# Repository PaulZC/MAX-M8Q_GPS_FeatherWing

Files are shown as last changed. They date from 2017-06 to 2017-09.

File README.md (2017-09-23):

# MAX-M8Q GPS FeatherWing

A clone of the Adafruit Ultimate GPS FeatherWing but with the u-blox MAX-M8Q (external antenna) replacing the GlobalTop FGPMMOPA6H

**23-09-2017: Updated PCB now includes: pull-up resistors for SCL and SDA; a decoupling capacitor for VCC_RF; a test pad for SAFEBOOT**

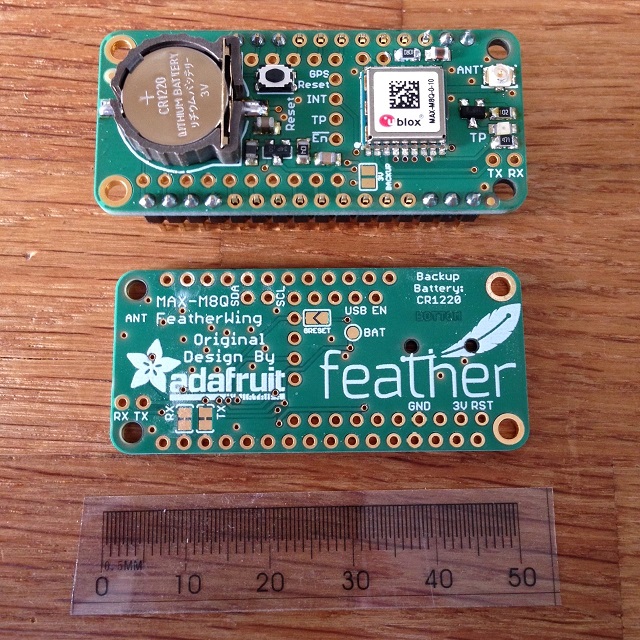
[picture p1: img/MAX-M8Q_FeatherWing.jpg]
MAX-M8Q_FeatherWing


See [MAX-M8Q_GPS_FeatherWing.pdf](https://github.com/PaulZC/MAX-M8Q_GPS_FeatherWing/blob/master/MAX-M8Q_GPS_FeatherWing.pdf) for the BOM etc.

The [Eagle](https://github.com/PaulZC/MAX-M8Q_GPS_FeatherWing/tree/master/Eagle) directory contains the schematic and pcb design

The [Arduino](https://github.com/PaulZC/MAX-M8Q_GPS_FeatherWing/tree/master/Arduino) directory contains code for the [Adafruit Feather M0 Adalogger](https://www.adafruit.com/products/2796) which will log your route to SD card in GPX and CSV format
- https://www.adafruit.com/products/2796
- https://learn.adafruit.com/adafruit-feather-m0-adalogger

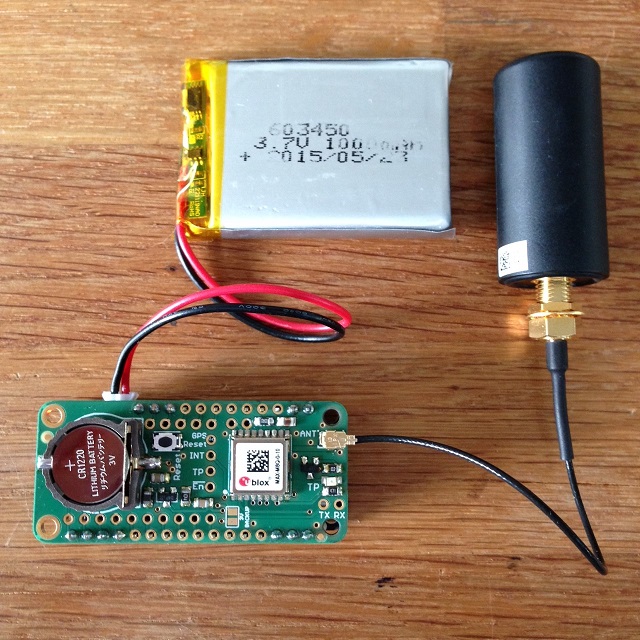
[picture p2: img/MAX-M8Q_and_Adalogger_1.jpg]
MAX-M8Q_and_Adalogger_1


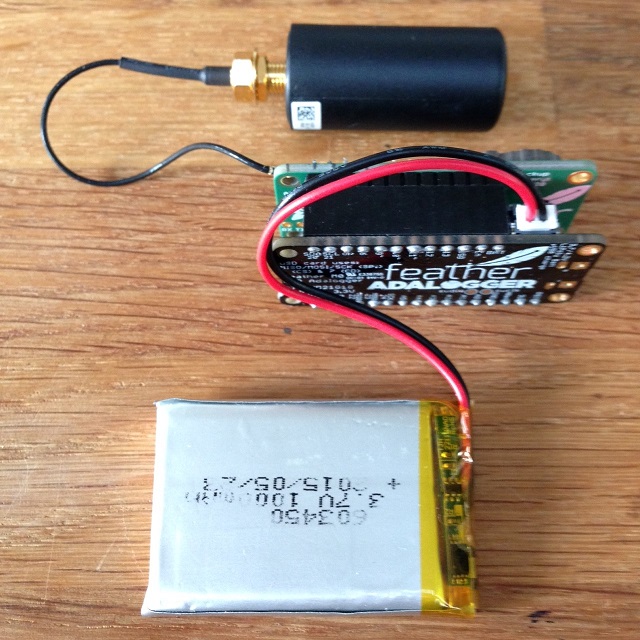
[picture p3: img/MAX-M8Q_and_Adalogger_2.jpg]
MAX-M8Q_and_Adalogger_2


Useful documentation about the MAX-M8Q and its protocol specification can be found at:
- https://www.u-blox.com/en/files/max-m8datasheetubx-13004644pdf
- https://www.u-blox.com/en/files/max-m8himubx-13004876pdf
- https://www.u-blox.com/en/files/u-bloxm8receiverdescrprotspecubx-13003221publicpdf

Based on an original design by Adafruit Industries:
- https://www.adafruit.com/product/3133
- https://learn.adafruit.com/adafruit-ultimate-gps-featherwing
- https://github.com/adafruit/Adafruit-Ultimate-GPS-FeatherWing-PCB

Distributed under a Creative Commons Attribution, Share-Alike license

Adafruit invests time and resources providing this open source design, please support Adafruit and open-source hardware by purchasing products from Adafruit!

Enjoy!

**_Paul_**

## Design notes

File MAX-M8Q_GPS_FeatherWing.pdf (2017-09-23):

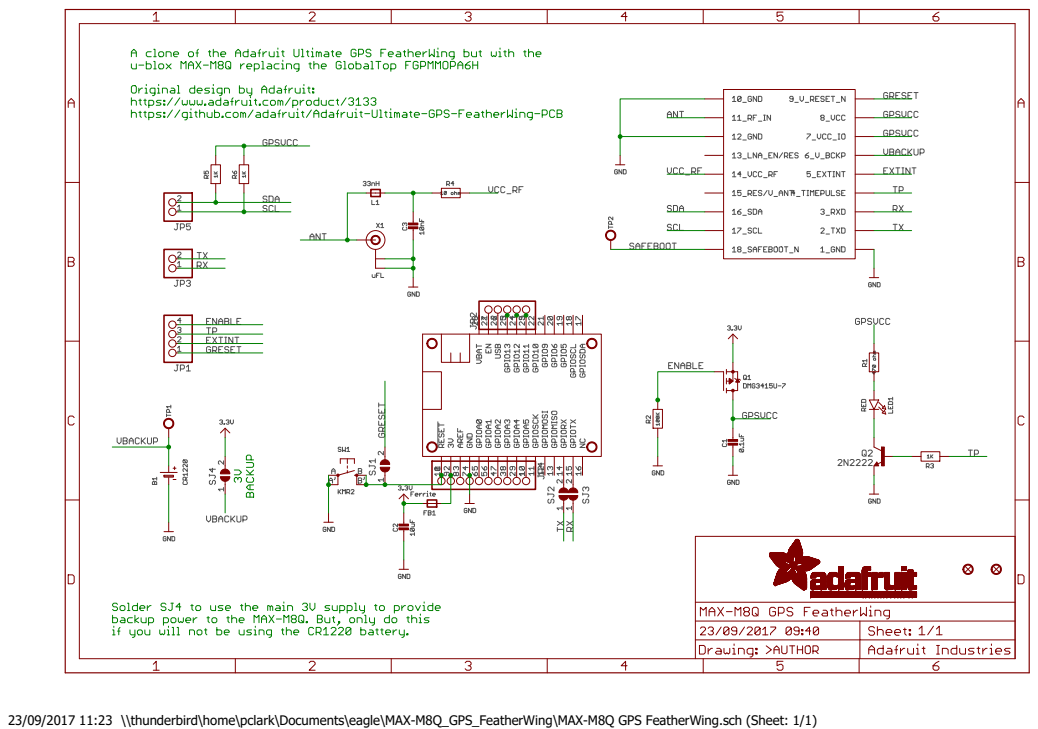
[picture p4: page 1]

23/09/2017 11:23 \\thunderbird\home\pclark\Documents\eagle\MAX-M8Q_GPS_FeatherWing\MAX-M8Q GPS FeatherWing.sch (Sheet: 1/1)

Name | X | Y | Angle Package | Value | Farnell /
| | | | | Element 14 | Comments
FID1 | 1.65 | 16.89 | 0 FIDUCIAL | 1MM
FID2 | 46.51 | 1.06 | 0 FIDUCIAL | 1MM
B1 | 10.38 | 12.83 | 0 CR1220 Holder | | 2064722 | e.g. Multicomp CH291‐1220LF
C1 | 27.43 | 6.55 | 180 0805 | 0.1uF | 2496944 | e.g. Walsin 0805B104K500CT
C2 | 20.19 | 10.29 | 0 0805 | 10uF | 2496998 | e.g. Walsin 0805F106Z100CT
C3 | 41.63 | 19.43 | 0 0805 | 10nF | 2496939 | e.g. Walsin 0805B103K500CT
FB1 | 18.41 | 7.22 | 90 0805 | Ferrite | 1635734 | e.g. Wurth Elektronik 742792031 (300R @ 100MHz)
L1 | 44.52 | 18.52 | 270 0805 | 33nH | 2286465 | e.g. Coilcraft 0805HT‐33NTGLB
LED1 | 48.3 | 7.06 | 90 0805 (2.0x1.25) RED | 1716768 | e.g. Multicomp OVS‐0808
Q1 | 21.46 | 7.24 | 180 SOT23‐WIDE | DMG3415U‐7 | 1843688 | e.g. Diodes Inc DMG3415U‐7
Q2 | 44.1 | 7.8 | 180 SOT23‐BEC | 2N2222 | 9846700 | e.g. Fairchild MMBT2222A
R1 | 48.4 | 5.25 | 180 0805 | 470 ohm | 9334572 | e.g. Multicomp MC01W08055470R
R2 | 24.51 | 7.37 | 90 0805 | 100K | 9333738 | e.g. Multicomp MC01W08055100K
R3 | 48.36 | 8.88 | 180 0805 | 1K | 9333711 | e.g. Multicomp MC01W080551K
R4 | 37.13 | 19.43 | 180 0805 | 10 ohm | 9332421 | e.g. Multicomp MC01W0805110R
R5 | 45.76 | 12.97 | 0 0805 | 1K | 9333711 | e.g. Multicomp MC01W080551K
R6 | 45.8 | 11.04 | 0 0805 | 1K | 9333711 | e.g. Multicomp MC01W080551K
SW1 | 21.21 | 16.26 | 180 4.6X2.8 | | 1605470 | e.g. Multicomp MCIPTG23K‐V
U1 | 36.6 | 12.45 | 270 MAX‐M8Q | MAX‐M8Q | https://www.u‐blox.com/en/product/max‐m8‐series
X1 | 48.11 | 16.03 | 270 U.FL | uFL | 3908021 | e.g. Hirose U.FL‐R‐SMT(01)

Extras

B1 | | | CR1220 | 3V Lithium | 2065165 | e.g. Multicomp CR1220
uFL to SMA Adaptor | 2448785 | e.g. RF Solutions CBA‐UFLSMA‐1

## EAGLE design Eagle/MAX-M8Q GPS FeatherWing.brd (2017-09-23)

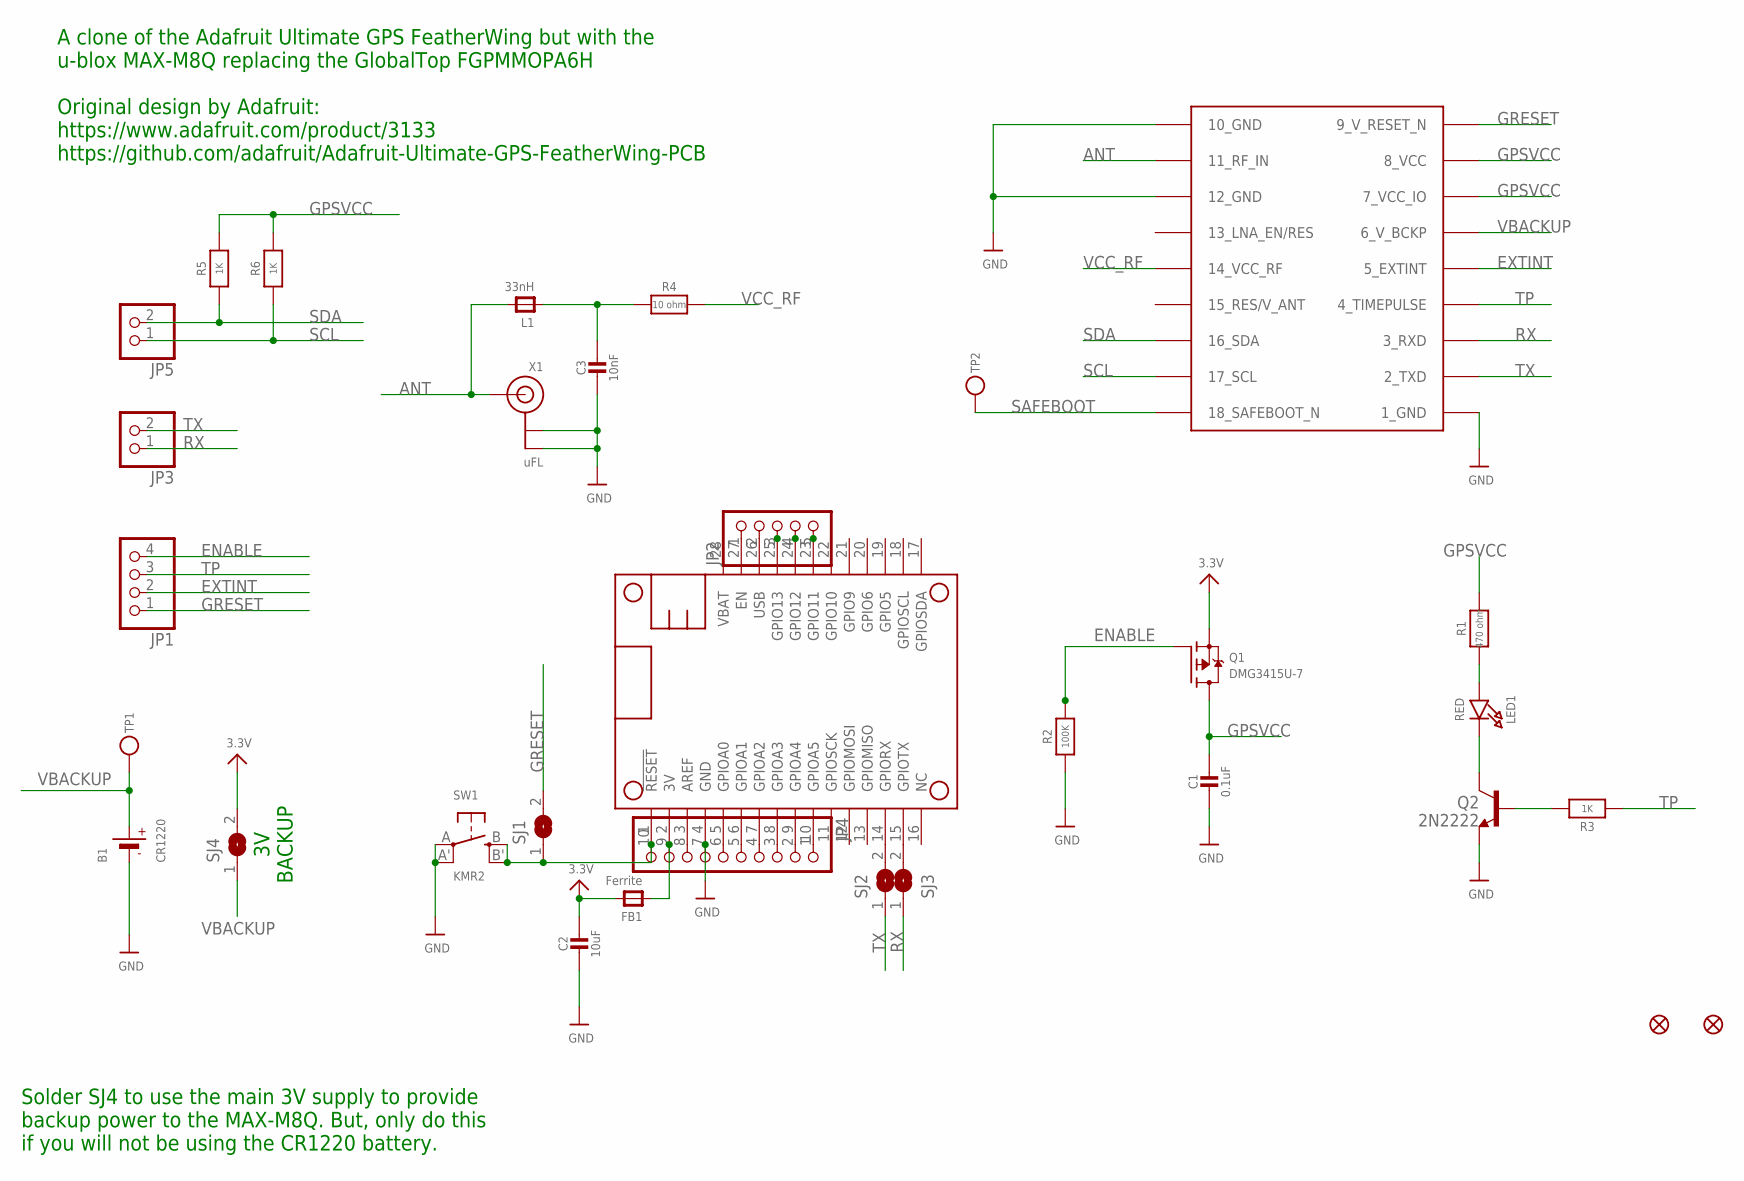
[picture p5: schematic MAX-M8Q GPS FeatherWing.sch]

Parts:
B1: CR1220; CR1220-2
C1: 0.1uF; 0805-NO
C2: 10uF; 0805-NO
C3: 10nF; 0805-NO
FB1: Ferrite; 0805-NO
FID1, FID2: FIDUCIAL""; FIDUCIAL_1MM
JP1: HEADER-1X4ROUND; 1X04_ROUND
JP2: HEADER-1X570MIL; 1X05_ROUND_70
JP3, JP5: HEADER-1X2ROUND; 1X02_ROUND
JP4: HEADER-1X10ROUND; 1X10_ROUND
L1: 33nH; 0805-NO
LED1: RED; CHIPLED_0805_NOOUTLINE
MS1: FEATHERWING
Q1: DMG3415U-7; SOT23-WIDE
Q2: 2N2222; SOT23-BEC
R1: 470 ohm; 0805-NO
R2: 100K; 0805-NO
R3, R5, R6: 1K; 0805-NO
R4: 10 ohm; 0805-NO
SJ1, SJ4: SOLDERJUMPER; SOLDERJUMPER_ARROW_NOPASTE
SJ2, SJ3: SOLDERJUMPERCLOSED; SOLDERJUMPER_CLOSEDWIRE
SW1: KMR2; BTN_KMR2_4.6X2.8
TP1, TP2: TESTPOINTROUND1.5MM; TESTPOINT_ROUND_1.5MM
U1: MAX-M8
X1: uFL; U.FL

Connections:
3.3V: C2.1, FB1.2, Q1.2 (S), SJ4.2
3V: FB1.1, JP4.9, MS1.2 (3V)
ANT: L1.2, U1.11_RF_IN, X1.3 (SIGNAL)
ENABLE: JP1.4, Q1.1 (G), R2.2
EXTINT: JP1.2, U1.5_EXTINT
GND: B1.-, C1.2, C2.2, C3.2, JP4.7, MS1.4 (GND), Q2.E, R2.1, SW1.A, SW1.A' (P1), U1.1_GND, U1.10_GND, U1.12_GND, X1.1 (GND), X1.2 (GND)
GPSVCC: C1.1, Q1.3 (D), R1.2, R5.2, R6.2, U1.7_VCC_IO, U1.8_VCC
GRESET: JP1.1, SJ1.2, U1.9_RESET_N (9_V_RESET_N)
unnamed: JP2.3, MS1.25 (GPIO13)
unnamed: LED1.A, R1.1
unnamed: JP2.4, MS1.24 (GPIO12)
unnamed: C3.1, L1.1, R4.1
unnamed: JP2.5, MS1.23 (GPIO11)
unnamed: JP4.1, MS1.10 (GPIOA5)
unnamed: JP4.2, MS1.9 (GPIOA4)
unnamed: JP4.3, MS1.8 (GPIOA3)
unnamed: JP4.4, MS1.7 (GPIOA2)
unnamed: JP4.5, MS1.6 (GPIOA1)
unnamed: JP4.6, MS1.5 (GPIOA0)
unnamed: JP4.10, MS1.1 (!RESET), SJ1.1, SW1.B (S), SW1.B' (S1)
unnamed: JP4.8, MS1.3 (AREF)
unnamed: JP2.1, MS1.27 (EN)
unnamed: MS1.14 (GPIORX), SJ2.2
unnamed: MS1.15 (GPIOTX), SJ3.2
unnamed: LED1.C, Q2.C
unnamed: Q2.B, R3.2
RX: JP3.1, SJ3.1, U1.3_RXD
SAFEBOOT: TP2.P$1, U1.18_SAFEBOOT_N
SCL: JP5.1, R6.1, U1.17_SCL
SDA: JP5.2, R5.1, U1.16_SDA
TP: JP1.3, R3.1, U1.4_TIMEPULSE
TX: JP3.2, SJ2.1, U1.2_TXD
USB: JP2.2, MS1.26 (USB)
VBACKUP: B1.+, SJ4.1, TP1.P$1, U1.6_V_BCKP
VCC_RF: R4.2, U1.14_VCC_RF

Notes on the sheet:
A clone of the Adafruit Ultimate GPS FeatherWing but with the u-blox MAX-M8Q replacing the GlobalTop FGPMMOPA6H Original design by Adafruit: https://www.adafruit.com/product/3133 https://github.com/adafruit/Adafruit-Ultimate-GPS-FeatherWing-PCB
3V BACKUP
Solder SJ4 to use the main 3V supply to provide backup power to the MAX-M8Q. But, only do this if you will not be using the CR1220 battery.

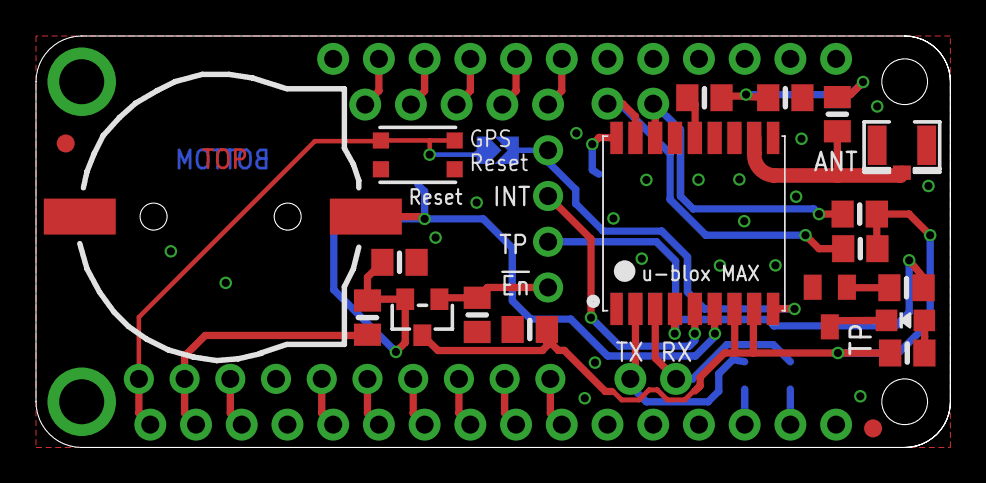
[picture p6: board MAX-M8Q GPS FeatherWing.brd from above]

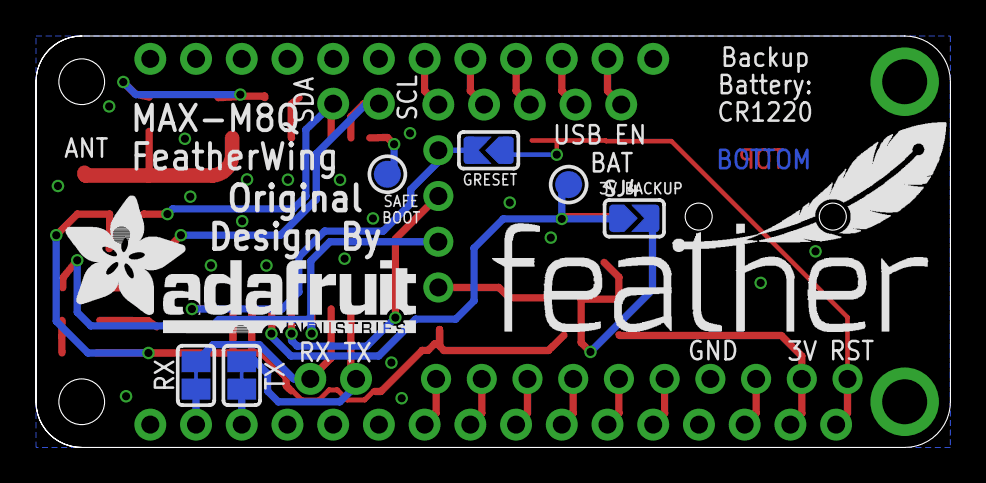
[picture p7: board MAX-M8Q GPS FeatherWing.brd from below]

Board: 2 copper layers, 50.8 x 22.9 mm, 32 parts (6 on the bottom side), 35 nets.

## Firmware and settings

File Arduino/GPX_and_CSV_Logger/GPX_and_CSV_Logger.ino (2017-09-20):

// Log GPS position to SD card in GPX track and CSV format

// This code is written for the Adalogger M0 Feather
// https://www.adafruit.com/products/2796
// and is based extensively on Adafruit's GPS_HardwareSerial_Parsing example
// https://github.com/adafruit/Adafruit_GPS/tree/master/examples/GPS_HardwareSerial_Parsing

// Works with both the Adafruit Ultimate GPS FeatherWing
// https://www.adafruit.com/product/3133
// and Paul's u-blox M8 FeatherWings
// https://github.com/PaulZC/SAM-M8Q_GPS_FeatherWing
// https://github.com/PaulZC/MAX-M8Q_GPS_FeatherWing

#define UBLOX // Comment this line out to select the Adafruit Ultimate GPS
//#define LOWPOWER // Comment this line out to disable u-blox M8 low power mode

// Leave the "#define GALILEO" uncommented to use: GPS + Galileo + GLONASS + SBAS
// Comment the "#define GALILEO" out to use the default u-blox M8 GNSS: GPS + SBAS + QZSS + GLONASS
#define GALILEO

//#define DEBUG // Comment this line out to disable extra serial debug messages

// Connect a normally-open push-to-close switch between swPin and GND.
// Press it to stop logging.
#define swPin 15 // Digital Pin 15 (0.2" away from the GND pin on the Adalogger)

// Include the Adafruit GPS Library
// https://github.com/adafruit/Adafruit_GPS
#include <Adafruit_GPS.h>
Adafruit_GPS GPS(&Serial1); // M0 hardware serial
     
// Set GPSECHO to 'false' to turn off echoing the GPS data to the Serial console
// Set to 'true' if you want to debug and listen to the raw GPS sentences
#define GPSECHO false
     
// this keeps track of whether we're using the interrupt
// off by default!
boolean usingInterrupt = false;

// SD card logging
#include <SPI.h>
#include <SD.h>
#define cardSelect 4
File gpx_dataFile;
File csv_dataFile;
char gpx_filename[] = "20000000/000000.gpx";
char csv_filename[] = "20000000/000000.csv";
char dirname[] = "20000000";
boolean fileReady = false;

// LEDs
#define RedLED 13 // The red LED on the Adalogger is connected to Digital Pin 13
#define GreenLED 8 // The green LED on the Adalogger is connected to Digital Pin 8

// Count number of valid fixes before starting to log (to avoid possible corrupt file names)
int valfix = 0;
#define maxvalfix 4 // Collect at least this many valid fixes before logging starts (must be >= 2)

// Track Point
long trkpt = 0;

#ifdef UBLOX // Definitions for u-blox M8 UBX-format (binary) messages

// Set Nav Mode to Portable
static const uint8_t setNavPortable[] = {
  0xB5, 0x62, 0x06, 0x24, 0x24, 0x00, 0xFF, 0xFF, 0x00, 0x03, 0x00, 0x00, 0x00, 0x00, 0x10, 0x27, 0x00, 0x00, 
  0x05, 0x00, 0xFA, 0x00, 0xFA, 0x00, 0x64, 0x00, 0x2C, 0x01, 0x00, 0x00, 0x00, 0x00, 0x00, 0x00, 0x00, 0x00, 
  0x00, 0x00, 0x00, 0x00, 0x00, 0x00 };
static const int len_setNav = 42;

// Set Nav Mode to Pedestrian
static const uint8_t setNavPedestrian[] = {
  0xB5, 0x62, 0x06, 0x24, 0x24, 0x00, 0xFF, 0xFF, 0x03, 0x03, 0x00, 0x00, 0x00, 0x00, 0x10, 0x27, 0x00, 0x00, 
  0x05, 0x00, 0xFA, 0x00, 0xFA, 0x00, 0x64, 0x00, 0x2C, 0x01, 0x00, 0x00, 0x00, 0x00, 0x00, 0x00, 0x00, 0x00, 
  0x00, 0x00, 0x00, 0x00, 0x00, 0x00 };

// Set Nav Mode to Automotive
static const uint8_t setNavAutomotive[] = {
  0xB5, 0x62, 0x06, 0x24, 0x24, 0x00, 0xFF, 0xFF, 0x04, 0x03, 0x00, 0x00, 0x00, 0x00, 0x10, 0x27, 0x00, 0x00, 
  0x05, 0x00, 0xFA, 0x00, 0xFA, 0x00, 0x64, 0x00, 0x2C, 0x01, 0x00, 0x00, 0x00, 0x00, 0x00, 0x00, 0x00, 0x00, 
  0x00, 0x00, 0x00, 0x00, 0x00, 0x00 };

// Set Nav Mode to Sea
static const uint8_t setNavSea[] = {
  0xB5, 0x62, 0x06, 0x24, 0x24, 0x00, 0xFF, 0xFF, 0x05, 0x03, 0x00, 0x00, 0x00, 0x00, 0x10, 0x27, 0x00, 0x00, 
  0x05, 0x00, 0xFA, 0x00, 0xFA, 0x00, 0x64, 0x00, 0x2C, 0x01, 0x00, 0x00, 0x00, 0x00, 0x00, 0x00, 0x00, 0x00, 
  0x00, 0x00, 0x00, 0x00, 0x00, 0x00 };

// Set Nav Mode to Airborne <1G
static const uint8_t setNavAir[] = {
  0xB5, 0x62, 0x06, 0x24, 0x24, 0x00, 0xFF, 0xFF, 0x06, 0x03, 0x00, 0x00, 0x00, 0x00, 0x10, 0x27, 0x00, 0x00, 
  0x05, 0x00, 0xFA, 0x00, 0xFA, 0x00, 0x64, 0x00, 0x2C, 0x01, 0x00, 0x00, 0x00, 0x00, 0x00, 0x00, 0x00, 0x00, 
  0x00, 0x00, 0x00, 0x00, 0x00, 0x00 };

// Set NMEA Config
// Set trackFilt to 1 to ensure course (COG) is always output
// Set Main Talker ID to 'GP' instead of 'GN'
static const uint8_t setNMEA[] = {
  0xb5, 0x62, 0x06, 0x17, 0x14, 0x00, 0x20, 0x40, 0x00, 0x02, 0x00, 0x00, 0x00, 0x00, 0x00, 0x01, 0x01, 0x01,
  0x00, 0x00, 0x00, 0x00, 0x00, 0x00, 0x00, 0x00 };
static const int len_setNMEA = 26;

// Set Low Power Mode
// Use this with caution
// Putting the M8 into low power mode before a fix has been established can cause it to reset after 10secs (searchPeriod)
static const uint8_t setLP[] = { 0xb5, 0x62, 0x06, 0x11, 0x02, 0x00, 0x48, 0x01 };
static const int len_setLP = 8;

// Set GNSS Config to GPS + Galileo + GLONASS + SBAS (Causes the M8 to restart!)
static const uint8_t setGNSS[] = {
  0xb5, 0x62, 0x06, 0x3e, 0x3c, 0x00,
  0x00, 0x20, 0x20, 0x07,
  0x00, 0x08, 0x10, 0x00, 0x01, 0x00, 0x01, 0x01,
  0x01, 0x01, 0x03, 0x00, 0x01, 0x00, 0x01, 0x01,
  0x02, 0x04, 0x08, 0x00, 0x01, 0x00, 0x01, 0x01,
  0x03, 0x08, 0x10, 0x00, 0x00, 0x00, 0x01, 0x01,
  0x04, 0x00, 0x08, 0x00, 0x00, 0x00, 0x01, 0x03,
  0x05, 0x00, 0x03, 0x00, 0x00, 0x00, 0x01, 0x05,
  0x06, 0x08, 0x0e, 0x00, 0x01, 0x00, 0x01, 0x01 };
static const int len_setGNSS = 66;

// Send message in u-blox UBX format
// Calculates and appends the two checksum bytes
// Doesn't add the 0xb5 and 0x62 sync chars (these need to be included at the start of the message)
void sendUBX(const uint8_t *message, const int len) {
  int csum1 = 0; // Checksum bytes
  int csum2 = 0;
#ifdef DEBUG
    Serial.print("Sending UBX packet: 0x");
#endif
  for (int i=0; i<len; i++) { // For each byte in the message
    Serial1.write(message[i]); // Write the byte
#ifdef DEBUG // DEBUG: print the message byte in HEX format
    if (message[i] < 16) {Serial.print("0");}
    Serial.print(message[i], HEX);
    Serial.print(", 0x");
#endif
    if (i >= 2) { // Don't include the sync chars in the checksum
      csum1 = csum1 + message[i]; // Update the checksum bytes
      csum2 = csum2 + csum1;
    }
  }
  csum1 = csum1 & 0xff; // Limit checksums to 8-bits
  csum2 = csum2 & 0xff;
  Serial1.write((uint8_t)csum1); // Send the checksum bytes
  Serial1.write((uint8_t)csum2);
#ifdef DEBUG // DEBUG: print the checksum bytes in HEX format
  if (csum1 < 16) {Serial.print("0");}
  Serial.print((uint8_t)csum1, HEX);
  Serial.print(", 0x");
  if (csum2 < 16) {Serial.print("0");}
  Serial.println((uint8_t)csum2, HEX);
#endif
}

#endif

void setup()
{
  // initialize digital pins RedLED and GreenLED as outputs.
  pinMode(RedLED, OUTPUT); // Red LED
  pinMode(GreenLED, OUTPUT); // Green LED
  // flash red and green LEDs on reset
  for (int i=0; i <= 4; i++) {
    digitalWrite(RedLED, HIGH);
    delay(200);
    digitalWrite(RedLED, LOW);
    digitalWrite(GreenLED, HIGH);
    delay(200);
    digitalWrite(GreenLED, LOW);
  }

  // initialize swPin as an input for the stop switch
  pinMode(swPin, INPUT_PULLUP);

  delay(10000); // Allow 10 sec for user to open serial monitor
  
  // connect at 115200 so we can read the GPS fast enough and echo without dropping chars
  Serial.begin(115200);
  Serial.println("Log GPS Position to SD card in GPX and CSV format");
  Serial.println("Green LED = GPS Fix");
  Serial.println("Red LED Flash = SD Write");
  Serial.println("Continuous Red indicates a problem or that the stop button has been pressed.");

  Serial.println("Initializing GPS...");

#ifdef UBLOX

  // u-blox M8 Init
  // 9600 is the default baud rate for u-blox M8
  GPS.begin(9600);
  // Disable all messages except GGA and RMC
  GPS.sendCommand("$PUBX,40,GLL,0,0,0,0*5C"); // Disable GLL
  delay(100);
  GPS.sendCommand("$PUBX,40,ZDA,0,0,0,0*44"); // Disable ZDA
  delay(100);
  GPS.sendCommand("$PUBX,40,VTG,0,0,0,0*5E"); // Disable VTG
  delay(100);
  GPS.sendCommand("$PUBX,40,GSV,0,0,0,0*59"); // Disable GSV
  delay(100);
  GPS.sendCommand("$PUBX,40,GSA,0,0,0,0*4E"); // Disable GSA
  delay(100);
  GPS.sendCommand("$PUBX,40,GGA,0,5,0,0*5F");  // Set GPGGA message rate to 5 (secs) - comment out for 1 sec logging
  delay(100);
  GPS.sendCommand("$PUBX,40,RMC,0,5,0,0*42");  // Set GPRMC message rate to 5 (secs) - comment out for 1 sec logging
  delay(100);
  sendUBX(setNavPortable, len_setNav); // Set Portable Navigation Mode
  //sendUBX(setNavPedestrian, len_setNav); // Set Pedestrian Navigation Mode
  //sendUBX(setNavAutomotive, len_setNav); // Set Automotive Navigation Mode
  //sendUBX(setNavSea, len_setNav); // Set Sea Navigation Mode
  //sendUBX(setNavAir, len_setNav); // Set Airborne <1G Navigation Mode
  delay(100);
  sendUBX(setNMEA, len_setNMEA); // Set NMEA configuration (use GP prefix instead of GN otherwise parsing will fail)
#ifdef GALILEO
  delay(100);
  sendUBX(setGNSS, len_setGNSS); // Set GNSS - causes M8 to restart!
  delay(2000); // Wait an extra 2 seconds for GNSS to restart
#endif
  delay(1100);
  while(Serial1.available()){Serial1.read();} // Flush RX buffer so we don't confuse GPS.parse with UBX acknowledgements

#else

  // Adafruit Ultimate GPS Init
  // 9600 NMEA is the default baud rate for Adafruit MTK GPS's- some use 4800
  GPS.begin(9600);
  // turn on RMC (recommended minimum) and GGA (fix data) including altitude
  GPS.sendCommand(PMTK_SET_NMEA_OUTPUT_RMCGGA);
  // Set the update rate
  //GPS.sendCommand(PMTK_SET_NMEA_UPDATE_1HZ); // 1 Hz update rate
  GPS.sendCommand(PMTK_SET_NMEA_UPDATE_200_MILLIHERTZ); // 5 sec update rate
  // Disable updates on antenna status
  GPS.sendCommand(PGCMD_NOANTENNA);

#endif

  Serial.println("GPS initialized!");

  // flash the red LED during SD initialisation
  digitalWrite(RedLED, HIGH);

  // Initialise SD card
  Serial.println("Initializing SD card...");
  // See if the SD card is present and can be initialized:
  if (!SD.begin(cardSelect)) {
    Serial.println("Panic!! SD Card Init failed, or not present!");
    // don't do anything more:
    while(1);
  }
  Serial.println("SD Card initialized!");

  // turn red LED off
  digitalWrite(RedLED, LOW);

  Serial.println("Waiting for GPS fix...");
}
     
void loop() // run over and over again
{
  // Check if stop switch has been pressed
  if (digitalRead(swPin) == LOW) {
    Serial.println("Stop switch pressed! Waiting for reset...");
    digitalWrite(RedLED, HIGH); // turn the red led on
    while(1); // wait for reset
  }
  
  // read data from the GPS in the 'main loop'
  char c = GPS.read();
  // if you want to debug, this is a good time to do it!
  if (GPSECHO)
    if (c) Serial.print(c);
  // if a sentence is received, we can check the checksum, parse it...
  if (GPS.newNMEAreceived()) {
    // Let the arrival of an new NMEA message be our second marker
    char *lastNMEA = GPS.lastNMEA(); // Make a copy of the string in case a new one arrives during parse (possibly redundant?)
    if (!GPS.parse(lastNMEA)) // this also sets the newNMEAreceived() flag to false
      return; // we can fail to parse a sentence in which case we should just wait for another

    // Choose whether to log on the arrival of the GGA or the RMC message
    // (choose whichever one is sent out second by the GPS)
#ifdef UBLOX
    if (strstr(lastNMEA,"$GPGGA")) { // u-blox M8: wait for a new GGA message
#else
    if (strstr(lastNMEA,"$GPRMC")) { // Ultimate GPS: wait for a new RMC message
#endif

#ifdef DEBUG
      Serial.print("\nTime: ");
      Serial.print(GPS.hour, DEC); Serial.print(':');
      Serial.print(GPS.minute, DEC); Serial.print(':');
      Serial.print(GPS.seconds, DEC); Serial.print('.');
      Serial.println(GPS.milliseconds);
      Serial.print("Date: ");
      Serial.print(GPS.day, DEC); Serial.print('/');
      Serial.print(GPS.month, DEC); Serial.print("/20");
      Serial.println(GPS.year, DEC);
      Serial.print("Fix: "); Serial.print((int)GPS.fix);
      Serial.print(" Quality: "); Serial.println((int)GPS.fixquality);
      if (GPS.fix) {
        Serial.print("Location: ");
        Serial.print(GPS.latitude, 4); Serial.print(GPS.lat);
        Serial.print(", ");
        Serial.print(GPS.longitude, 4); Serial.println(GPS.lon);
        Serial.print("Speed (knots): "); Serial.println(GPS.speed);
        Serial.print("Angle: "); Serial.println(GPS.angle);
        Serial.print("Altitude: "); Serial.println(GPS.altitude);
        Serial.print("Satellites: "); Serial.println((int)GPS.satellites);
        Serial.print("HDOP: "); Serial.println(GPS.HDOP);
      }
#endif

      // read battery voltage
      float vbat = analogRead(A7) * (2.0 * 3.3 / 1023.0);
#ifdef DEBUG
      Serial.print("Battery(V): ");
      Serial.println(vbat, 2);
#endif
    
      // turn green LED on to indicate GPS fix
      if (GPS.fix) {
        digitalWrite(GreenLED, HIGH);
        // increment valfix and cap at maxvalfix
        // don't do anything fancy in terms of decrementing valfix as we want to keep logging even if the fix is lost
        valfix += 1;
        if (valfix > maxvalfix) valfix = maxvalfix;
      }
      else {
        digitalWrite(GreenLED, LOW);
      }

#ifdef UBLOX
#ifdef LOWPOWER
      // Check if Low Power Mode can be started on the u-blox M8
      if (valfix == (maxvalfix - 1)) { // Only do this once
        sendUBX(setLP, len_setLP);
      }
#endif
#endif

      if (valfix == maxvalfix) { // wait until we have enough valid fixes to avoid possible filename corruption

        // do the divides once to save time
        char GPShourT = GPS.hour/10 + '0';
        char GPShourU = GPS.hour%10 + '0';
        char GPSminT = GPS.minute/10 + '0';
        char GPSminU = GPS.minute%10 + '0';
        char GPSsecT = GPS.seconds/10 + '0';
        char GPSsecU = GPS.seconds%10 + '0';
        char GPSyearT = GPS.year/10 +'0';
        char GPSyearU = GPS.year%10 +'0';
        char GPSmonT = GPS.month/10 +'0';
        char GPSmonU = GPS.month%10 +'0';
        char GPSdayT = GPS.day/10 +'0';
        char GPSdayU = GPS.day%10 +'0';

        // build the gpx data string
        String gpx_dataString = "<trkpt lat=\"";
        gpx_dataString += String(GPS.latitudeDegrees, 6);
        gpx_dataString += "\" lon=\"";
        gpx_dataString += String(GPS.longitudeDegrees, 6);
        gpx_dataString += "\">\n";
        gpx_dataString += "<name>";
        gpx_dataString += String(trkpt);
        gpx_dataString += "</name>\n";
        gpx_dataString += "<time>20";
        gpx_dataString += GPSyearT; gpx_dataString += GPSyearU; gpx_dataString += "-";
        gpx_dataString += GPSmonT; gpx_dataString += GPSmonU; gpx_dataString += "-";
        gpx_dataString += GPSdayT; gpx_dataString += GPSdayU; gpx_dataString += "T";
        gpx_dataString += GPShourT; gpx_dataString += GPShourU; gpx_dataString += ":";
        gpx_dataString += GPSminT; gpx_dataString += GPSminU; gpx_dataString += ":";
        gpx_dataString += GPSsecT; gpx_dataString += GPSsecU; gpx_dataString += ".";
        gpx_dataString += String((int)GPS.milliseconds); gpx_dataString += "Z</time>\n";
        gpx_dataString += "<ele>";
        gpx_dataString += String(GPS.altitude, 1);
        gpx_dataString += "</ele>\n";
        gpx_dataString += "<fix>";
        if (!GPS.fix) {
          gpx_dataString += "none";
        }
        else {
          gpx_dataString += "3d";
        }
        gpx_dataString += "</fix>\n";
        gpx_dataString += "<sat>";
        gpx_dataString += String((int)GPS.satellites);
        gpx_dataString += "</sat>\n";
        gpx_dataString += "<hdop>";
        gpx_dataString += String(GPS.HDOP, 2);
        gpx_dataString += "</hdop>\n";
        gpx_dataString += "<desc>Battery voltage ";
        gpx_dataString += String(vbat, 2);
        gpx_dataString += "V</desc>\n";
        gpx_dataString += "</trkpt>\n";

        // build the csv data string
        String csv_dataString = "";
        csv_dataString += GPShourT; csv_dataString += GPShourU; csv_dataString += ':';
        csv_dataString += GPSminT; csv_dataString += GPSminU; csv_dataString += ':';
        csv_dataString += GPSsecT; csv_dataString += GPSsecU;
        //csv_dataString += '.'; csv_dataString += String(GPS.milliseconds, DEC); // comment this line out to ignore milliseconds
        csv_dataString += ' '; // separate time and date with a space (not a ',') to make life easier for numpy.loadtxt
        csv_dataString += GPSdayT; csv_dataString += GPSdayU; csv_dataString += '/';
        csv_dataString += GPSmonT; csv_dataString += GPSmonU; csv_dataString += "/20";
        csv_dataString += GPSyearT; csv_dataString += GPSyearU; csv_dataString += ',';
        csv_dataString += String(GPS.latitudeDegrees, 6); csv_dataString += ',';
        //csv_dataString += String(GPS.latitude, 4); csv_dataString += ','; csv_dataString += String(GPS.lat); csv_dataString += ',';
        csv_dataString += String(GPS.longitudeDegrees, 6); csv_dataString += ',';
        //csv_dataString += String(GPS.longitude, 4); csv_dataString += ','; csv_dataString += String(GPS.lon); csv_dataString += ',';
        csv_dataString += String(GPS.speed); csv_dataString += ',';
        csv_dataString += String(GPS.angle); csv_dataString += ',';
        csv_dataString += String(GPS.altitude); csv_dataString += ',';
        csv_dataString += String((int)GPS.fix); csv_dataString += ',';
        csv_dataString += String((int)GPS.fixquality); csv_dataString += ',';
        csv_dataString += String((int)GPS.satellites); csv_dataString += ',';
        csv_dataString += String(GPS.HDOP); csv_dataString += ',';
        csv_dataString += String(trkpt); csv_dataString += ',';
        csv_dataString += String(vbat, 2); csv_dataString += '\n';

        // flash red LED to indicate SD write (leave on if an error occurs)
        digitalWrite(RedLED, HIGH);

        // syntax checking:
        // check if voltage is > 3.55V, if not then don't try to write!
        if (vbat < 3.55) {
          fileReady = false; // Start new file when battery is recharged
          Serial.println("Low Battery!");
          return;
        }
        // check year
        if ((GPS.year < 16) || (GPS.year > 26)) return;
        // check month
        if (GPS.month > 12) return;
         // check day
        if (GPS.day > 31) return;
  
        if (!fileReady) {
          // filename is limited to 8.3 characters so use format: YYYYMMDD/HHMMSS.gpx
          gpx_filename[2] = GPSyearT;
          gpx_filename[3] = GPSyearU;
          gpx_filename[4] = GPSmonT;
          gpx_filename[5] = GPSmonU;
          gpx_filename[6] = GPSdayT;
          gpx_filename[7] = GPSdayU;
          gpx_filename[9] = GPShourT;
          gpx_filename[10] = GPShourU;
          gpx_filename[11] = GPSminT;
          gpx_filename[12] = GPSminU;
          gpx_filename[13] = GPSsecT;
          gpx_filename[14] = GPSsecU;
          
          csv_filename[2] = GPSyearT;
          csv_filename[3] = GPSyearU;
          csv_filename[4] = GPSmonT;
          csv_filename[5] = GPSmonU;
          csv_filename[6] = GPSdayT;
          csv_filename[7] = GPSdayU;
          csv_filename[9] = GPShourT;
          csv_filename[10] = GPShourU;
          csv_filename[11] = GPSminT;
          csv_filename[12] = GPSminU;
          csv_filename[13] = GPSsecT;
          csv_filename[14] = GPSsecU;

          dirname[2] = GPSyearT;
          dirname[3] = GPSyearU;
          dirname[4] = GPSmonT;
          dirname[5] = GPSmonU;
          dirname[6] = GPSdayT;
          dirname[7] = GPSdayU;
  
          // try to create subdirectory (even if it exists already)
          SD.mkdir(dirname);
          
          // Open the gpx file for writing
          gpx_dataFile = SD.open(gpx_filename, FILE_WRITE);
          
          // if the file is available, write to it:
          if (gpx_dataFile) {
            gpx_dataFile.print("<gpx>\n<trk>\n<trkseg>\n"); // write header
            gpx_dataFile.print("</trkseg>\n</trk>\n</gpx>\n"); // write footer
            gpx_dataFile.close();
            Serial.print("Logging to ");
            Serial.println(gpx_filename);
            delay(200); // Allow 0.2s for SD file to close
          }
          // if the file isn't open, pop up an error:
          else {
            Serial.println("Error opening GPX file (1)!");
          }
          
          // Open the csv file for writing
          csv_dataFile = SD.open(csv_filename, FILE_WRITE);
          
          // if the file is available, write to it:
          if (csv_dataFile) {
            csv_dataFile.print("HH:MM:SS DD/MM/YYYY,LAT,LON,SPEED,ANGLE,ALT,FIX,FIXQUAL,SAT,HDOP,TRKPT,BATV\n"); // write header
            csv_dataFile.close();
            Serial.print("Logging to ");
            Serial.println(csv_filename);
            fileReady = true;
            trkpt = 0;
            delay(200); // Allow 0.2s for SD file to close
          }
          // if the file isn't open, pop up an error:
          else {
            Serial.println("Error opening CSV file (1)!");
          }
        }
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

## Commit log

2017-06-24 First Release
    A clone of the Adafruit GPS FeatherWing incorporating the u-blox MAX-M8Q
    (external antenna)
    [MAX-M8Q GPS FeatherWing.brd, MAX-M8Q GPS FeatherWing.sch]
2017-06-25 Minor tweaks. Included BOM.
    [MAX-M8Q GPS FeatherWing.brd, MAX-M8Q GPS FeatherWing.sch]
2017-07-06 Updates
    Included the two fiducials in the tCReam layer. Included Arduino code
    which runs on the Adafruit M0 Feather Adalogger which will log your
    route to SD card in GPX and CSV format.
    [MAX-M8Q GPS FeatherWing.brd, MAX-M8Q GPS FeatherWing.sch]
2017-07-17 Tested and working!
    Updated the readme and included images of the tested PCB
2017-08-14 Added HDOP logging
    Arduino code now logs HDOP in both GPX and CSV files
2017-09-05 Updated GPX_and_CSV_Logger to include a stop switch.
2017-09-20 Updated the Arduino code.
    Updated the Arduino code. sendUBX now calculates the UBX packet
    checksums for you making it much easier to update the M8 configuration.
2017-09-23 Updated PCB
    Updated PCB now includes: pull-up resistors for SCL and SDA; a
    decoupling capacitor for VCC_RF; a test pad for SAFEBOOT.
    [MAX-M8Q GPS FeatherWing.brd, MAX-M8Q GPS FeatherWing.sch]
